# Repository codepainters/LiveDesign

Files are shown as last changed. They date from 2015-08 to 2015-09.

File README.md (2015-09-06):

Xilinx LiveDesing utils
-----------------------

This repository contains various files useful when working with
Xilinx version of the Altium LiveDesign board.

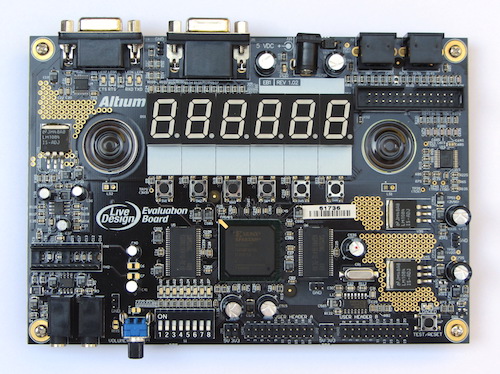
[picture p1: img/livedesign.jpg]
Altium board


The board is quite old, to be honest (I've bought mine a few years ago), 
but with Xilinx Spartan 3 FPGA (XC3S1000 in my case, there was also a smaller
XC3S400 edition) it is still quite powerful. It could have slightly better
peripherals, but well...

What's in this repo:

 * [docs](docs) - original docs from Altium
 * [jtag_pcb](jtag_pcb) - a project of small PCB converting Altium's silly 26-pin programming connector into standard Xilinx JTAG
 * [livedesign.ucf](livedesign.ucf) - UCF file for use with Xilinx WebPACK
 * [test](test) - simple test project

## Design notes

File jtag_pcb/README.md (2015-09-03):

This directory contains the schematic and PCB files for a simple 
JTAG pinout converter from Altium's to standard Xilinx 14-pin 
connector.

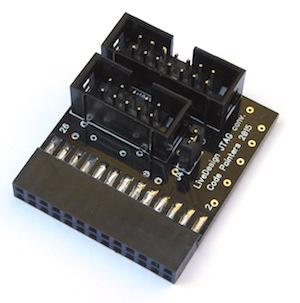
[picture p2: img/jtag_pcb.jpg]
JTAG PCB


Altium uses 26-pin IDC connector which maps directly to
a DB25 LPT plug. The pinout is as follows:

| Name | Pin | Pin | Name  |
|---|-----|-----|---|
| - | 1 | 2 | - |
| hTDI | 3 | 4 | hVREF |
| hTCK | 5 | 6 | - |
| hTMS | 7 | 8 | sTMS  |
| OE | 9 | 10  | GND |
| - | 11  | 12  | GND |
| sTDI | 13  | 14  | GND |
| - | 15  | 16  | GND |
| sTCK | 17  | 18  | GND |
| sTDO | 19  | 20  | GND |
| - | 21  | 22  | GND |
| - | 23  | 24  | GND |
| hTDO | 25  | 26  | - |

Note:
 
 * don't get confused by the pin numbering on the Altium schematics. They
   use the numbers corresponding to pins of the DB25 connector at 
   the other end of the flat cable. For normal IDC26 numbering use 
   the table above.

 * there are 2 sets of JTAG signals exposed - "hard" one is connected 
   to the FPGA's JTAG pins, this is the one to use to program the FPGA.
   Second one, referred to as "soft", is supposed to be used to debug 
   any soft-core CPU implemented in FPGA. It is connected to regular I/O
   pins: TMS - L21N, TCK - L24P, TDI - L21P, TDO - L17P.
 
 * pin 4 is pulled to `VCC` via 4k7 resistor, not sure what for, but 
   it seemed to be a good candidate for `VREF`. Unfortunately, it doesn't
   work as is (at least with the cable I use), see below.

 * pins 15, 21 and 23 are shorted together, but it's irrelevant for us

 * there is a 3-state buffer on board, OE connected to pin 9, it has 
   to be pulled low for anything to work 

The board is equipped with connectors for both JTAG chains:
 
 * IDC14 connector for "hard JTAG", compatible with Xilinx cables
 * IDC10 connector for "soft JTAG", using ARM JTAG pinout

The Xilinx cable requires 3.3V on JTAG `VREF` pin, and initially I planned
to use pin 4 as `VREF` source, unfortunately it doesn't work (scanning the chain,
as well as reading the ID etc. works fine, but actual programming fails).

There are two workarounds - one is to remove the `J4` jumper and connect
pin 2 of `J4` to any `VCC` point on LiveDesign board. Another workaround is to
short `R20S` on LiveDesign PCB.

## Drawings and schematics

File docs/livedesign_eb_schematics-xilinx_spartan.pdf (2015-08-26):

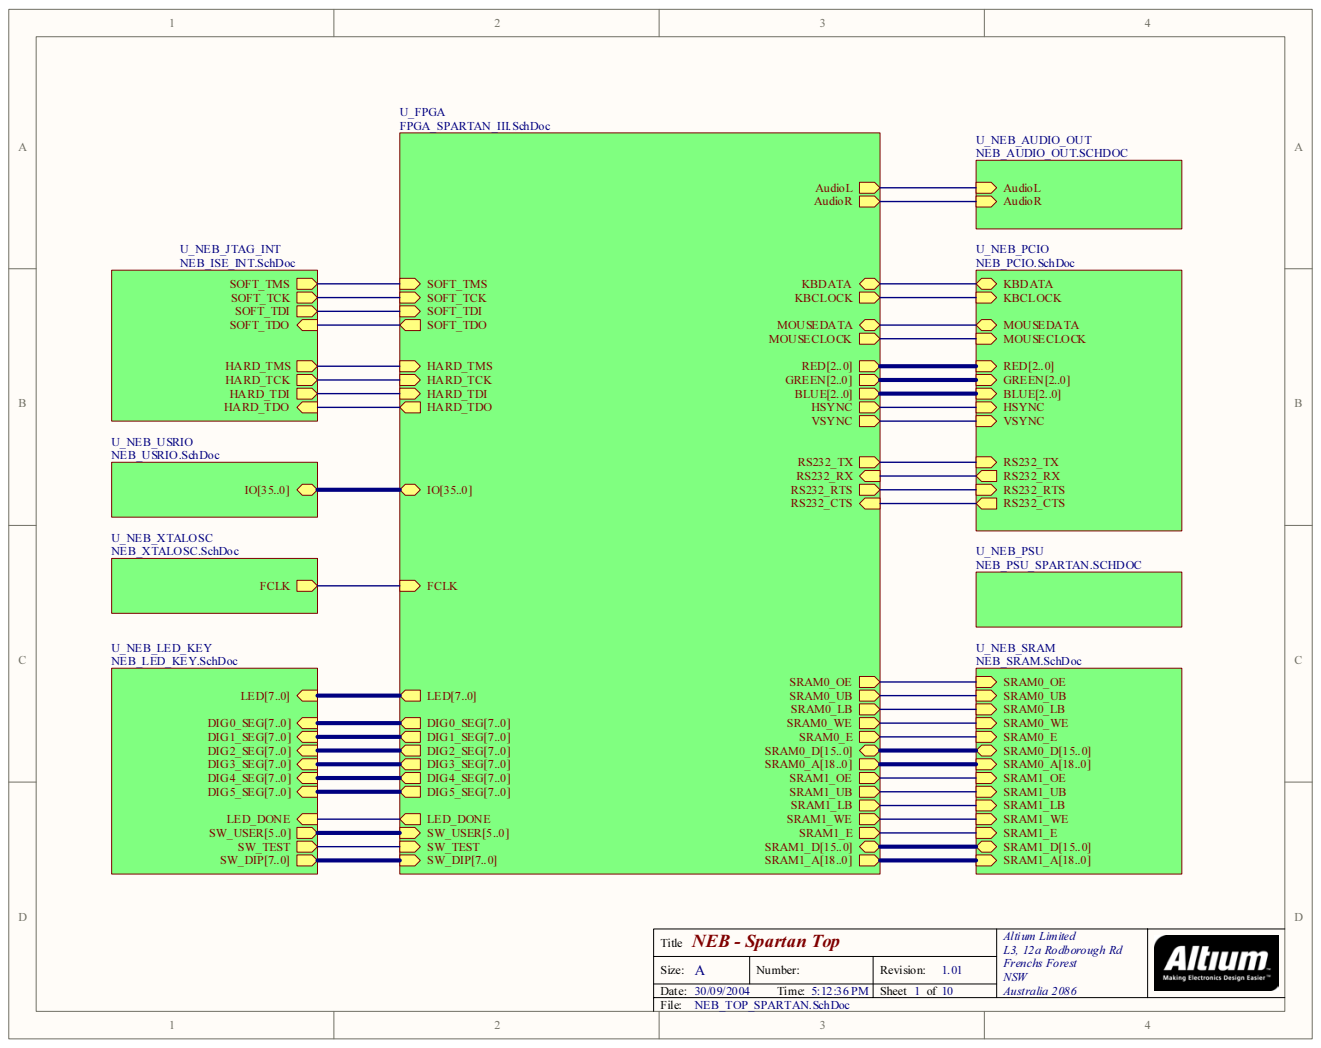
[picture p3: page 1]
Altium Limited L3, 12a Rodborough Rd Frenchs Forest NSW; Australia 2086; NEB_TOP_SPARTAN.SchDoc; Size:; Number:; Date: File:; Revision:; Time:; Sheet; SOFT_TCK SOFT_TDI; SOFT_TMS; SOFT_TDO; HARD_TMS HARD_TCK HARD_TDI HARD_TDO; U_NEB_JTAG_INT NEB_ISE_INT.SchDoc; AudioL AudioR; U_NEB_AUDIO_OUT NEB_AUDIO_OUT.SCHDOC; U_NEB_PSU NEB_PSU_SPARTAN.SCHDOC; LED[7..0]; SW_DIP[7..0]; DIG0_SEG[7..0] DIG1_SEG[7..0] DIG2_SEG[7..0] DIG3_SEG[7..0]; SW_TEST; SW_USER[5..0]; LED_DONE; DIG4_SEG[7..0] DIG5_SEG[7..0]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

NEB - Spartan Top
Title

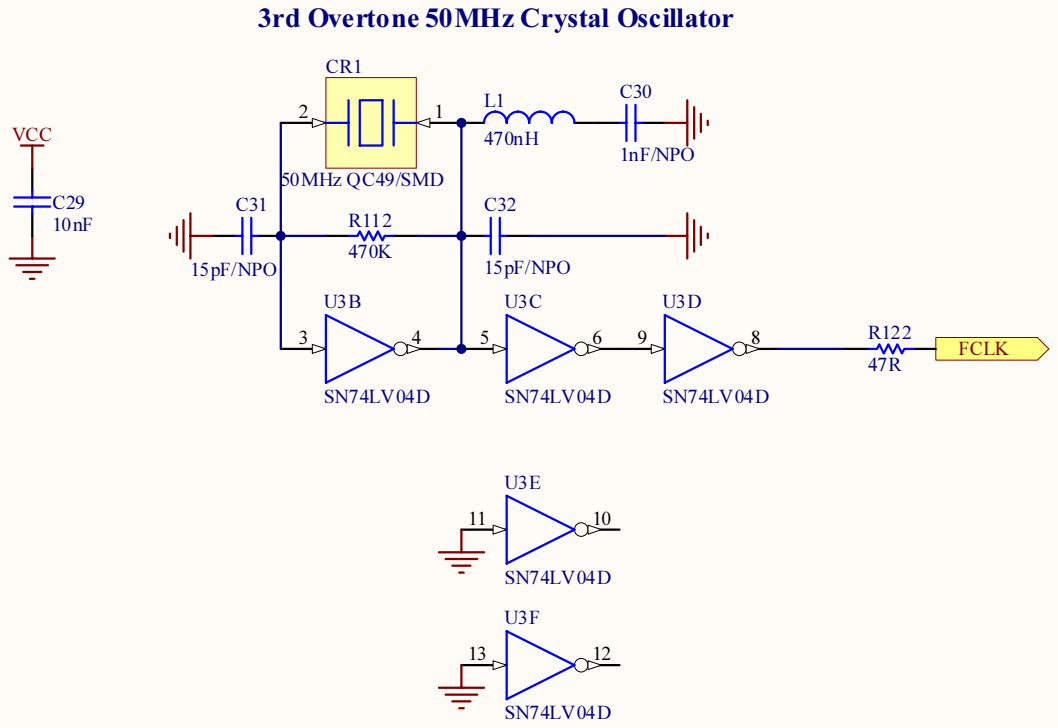
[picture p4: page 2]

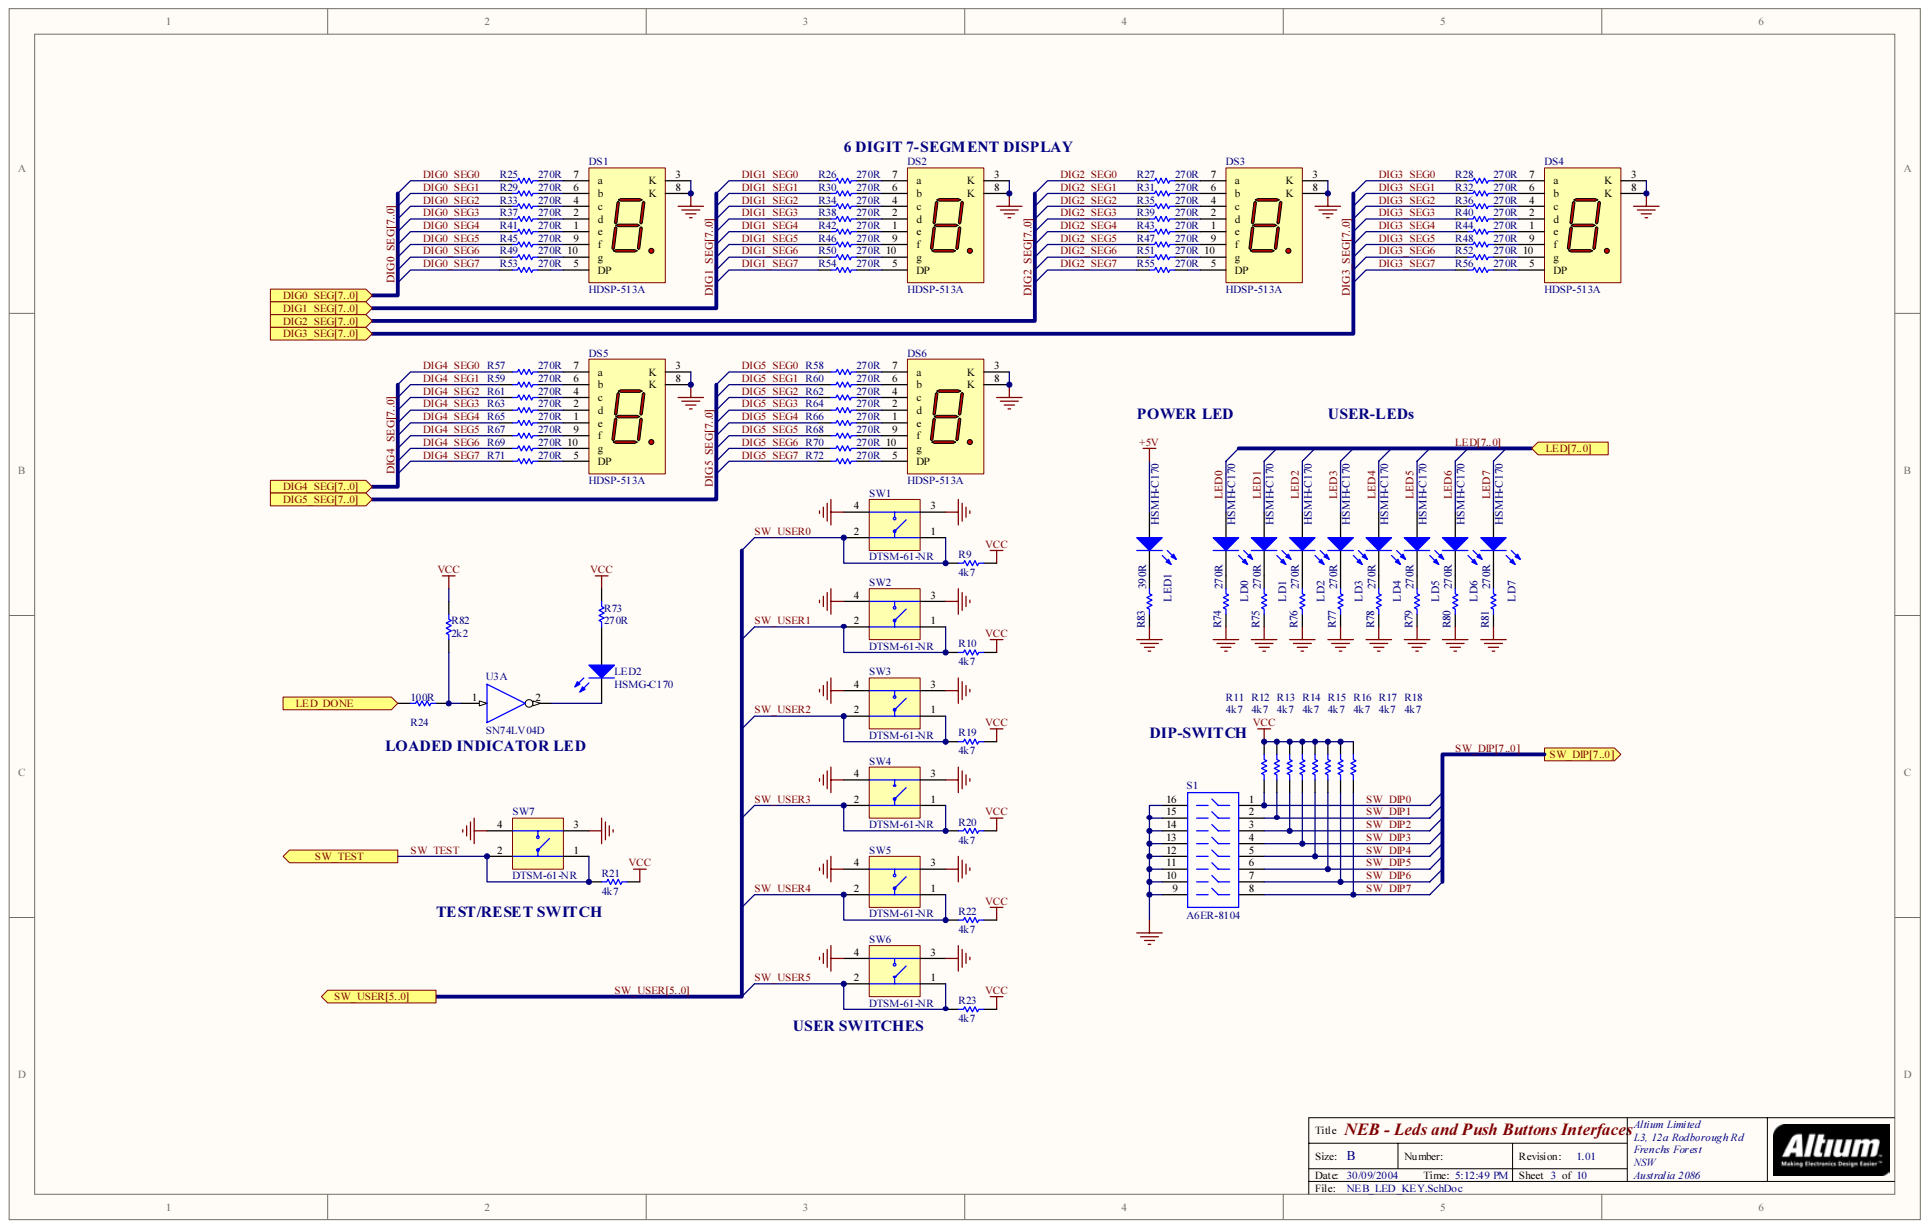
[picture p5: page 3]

NEB - Leds and Push Buttons Interfaces
Title

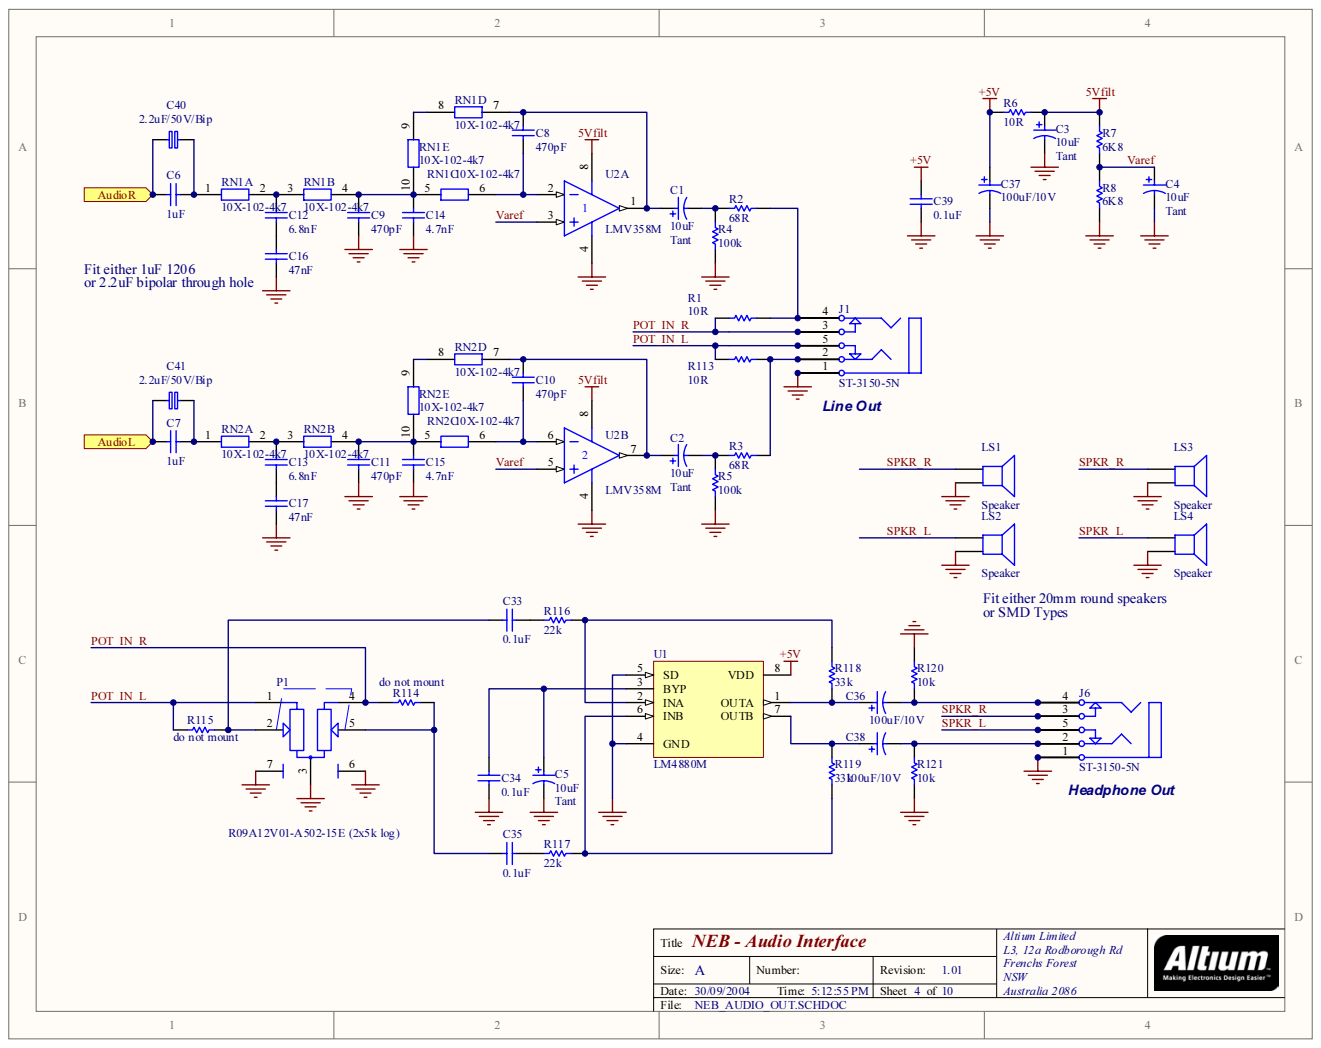
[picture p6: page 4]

Fit either 1uF 1206
or 2.2uF bipolar through hole

Speaker
Fit either 20mm round speakers
or SMD Types

# Printer Port JTAG Interface

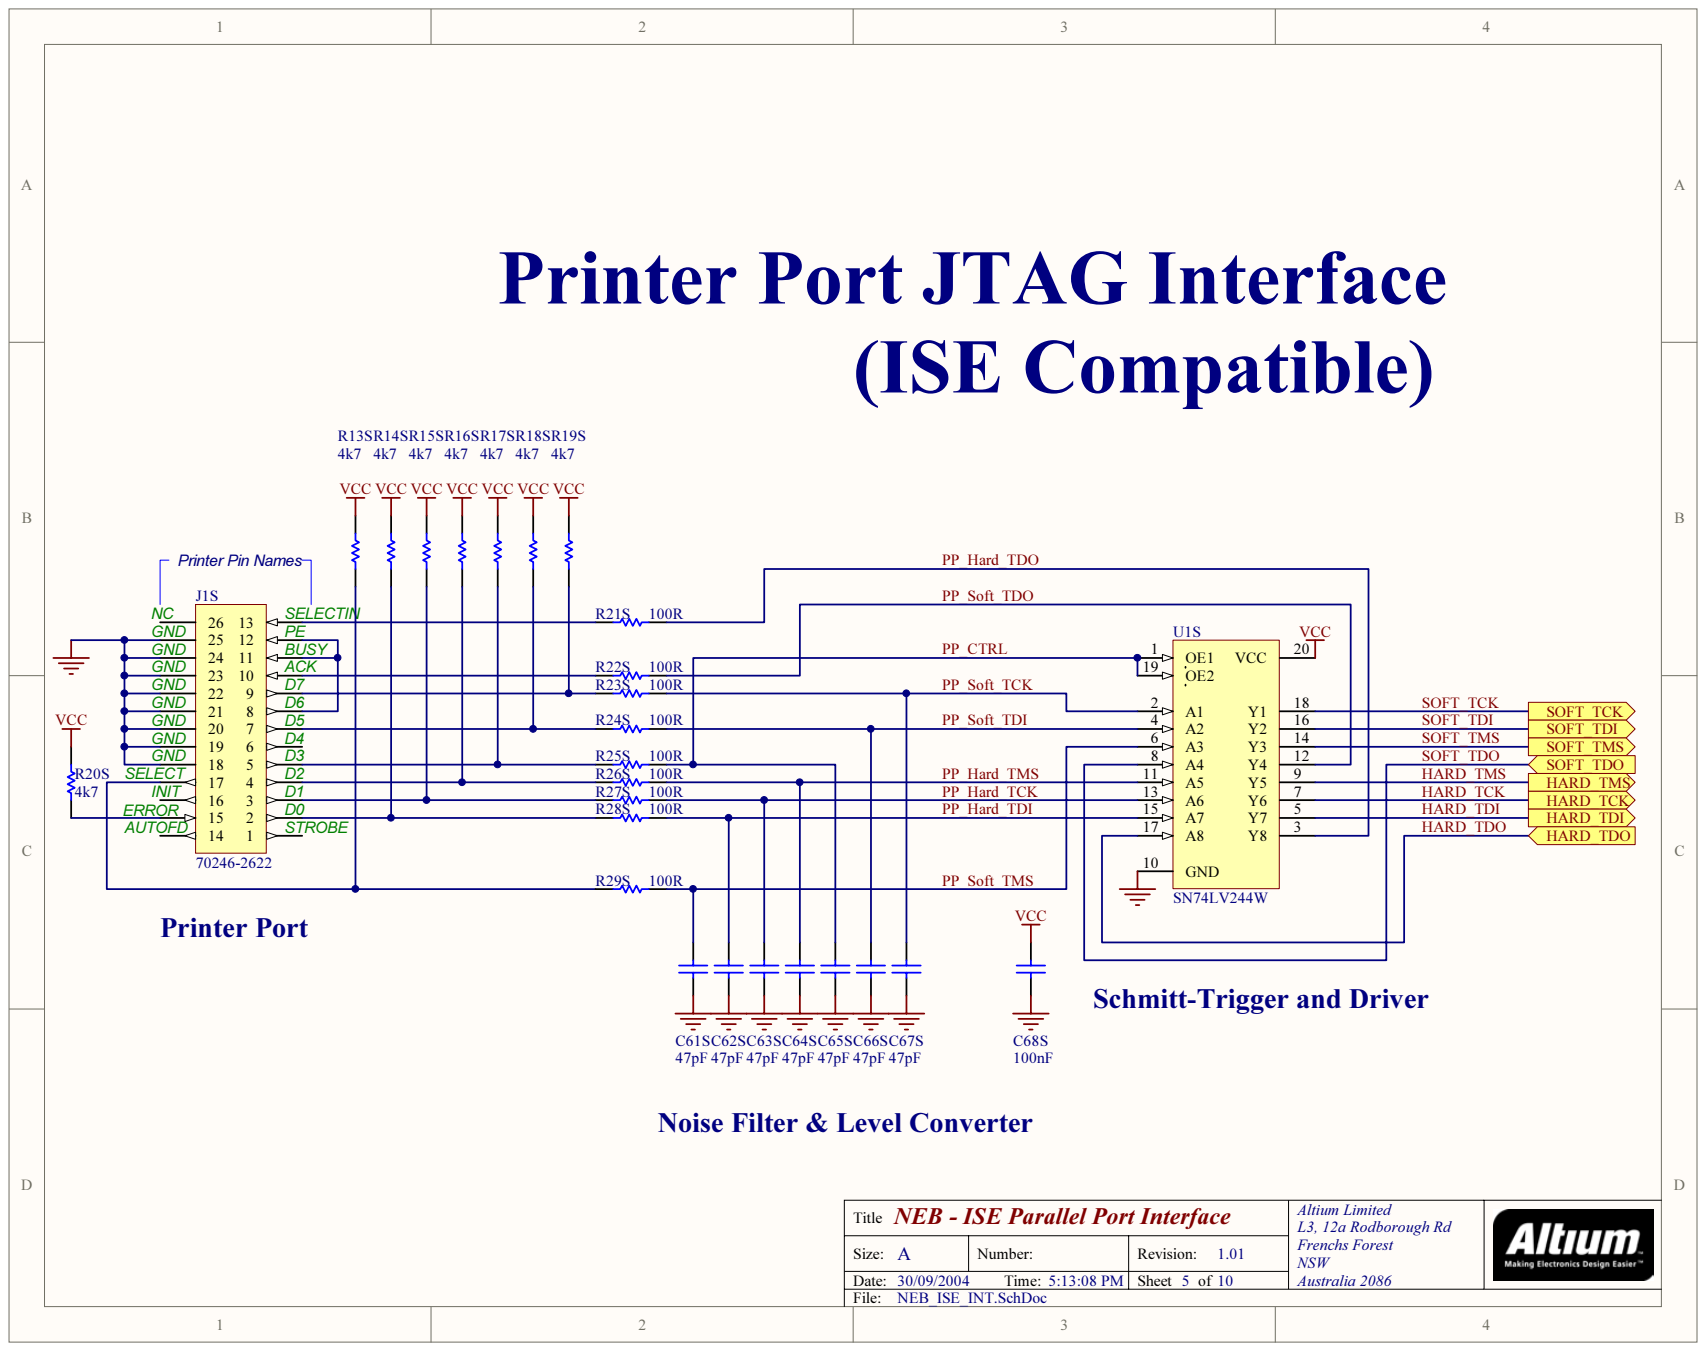
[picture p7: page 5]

PP_Soft_TDO

U1S PP_CTRL OE1 1 PP_Soft_TCK | VCC

Schmitt-Trigger and Driver

Noise Filter & Level Converter

NEB - ISE Parallel Port Interface

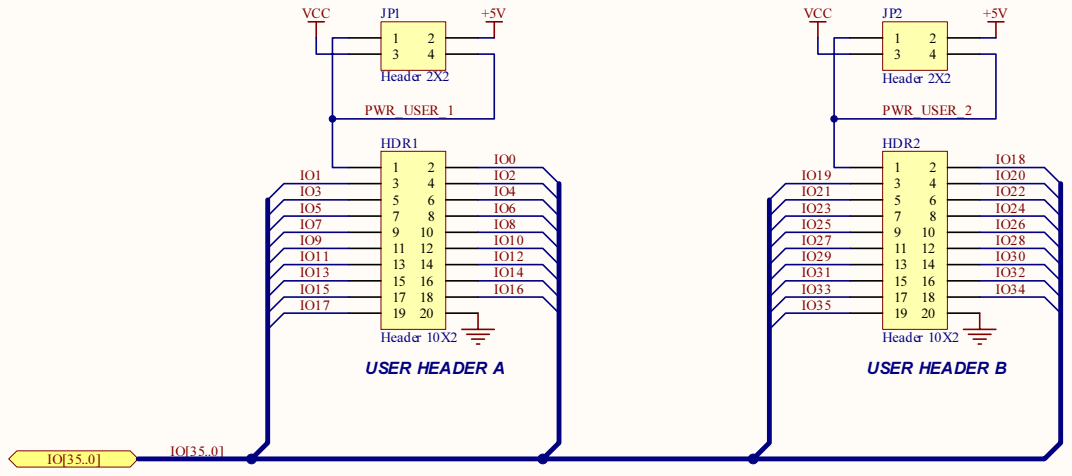
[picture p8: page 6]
Altium Limited L3, 12a Rodborough Rd Frenchs Forest; NEB_USRIO.SchDoc; Size:; Number:; Revision:; HDR1; Header 10X2; HDR2; VCC; USER HEADER A; USER HEADER B; Header 2X2; PWR_USER_1; PWR_USER_2

NEB - Users IO Interfaces
Title

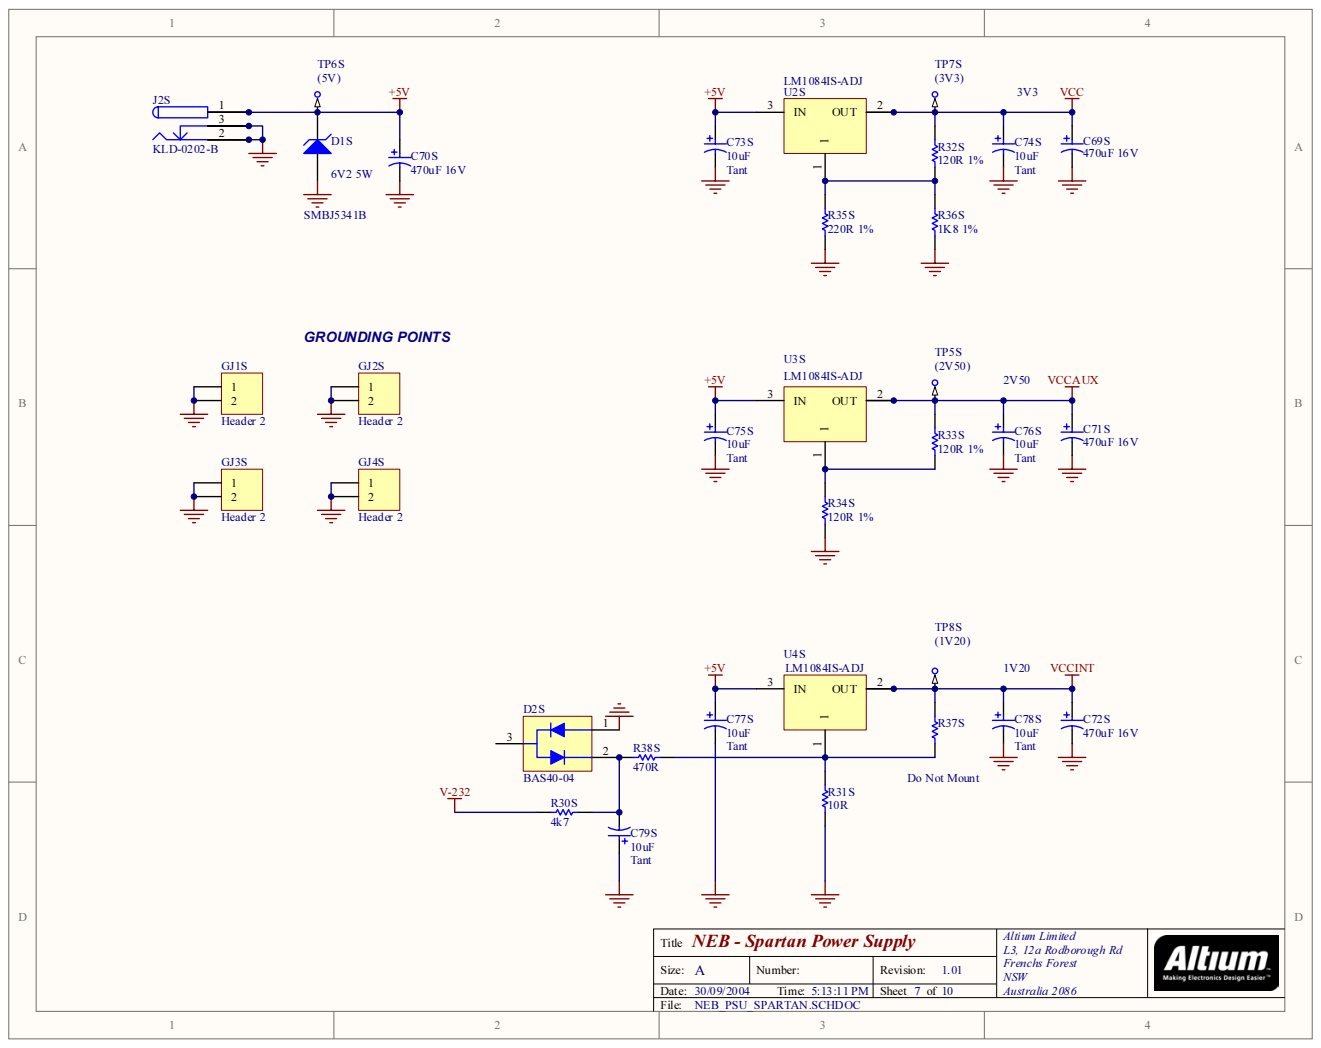
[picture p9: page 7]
Altium Limited L3, 12a Rodborough Rd Frenchs Forest; NEB_PSU_SPARTAN.SCHDOC; Size:; Number:; Revision:; VCC; Tant; VCCINT; Header 2; GROUNDING POINTS; VCCAUX; SMBJ5341B; KLD-0202-B; BAS40-04; OUT; LM1084IS-ADJ; U4S LM1084IS-ADJ; U3S LM1084IS-ADJ

Do Not Mount

NEB - Spartan Power Supply
Title

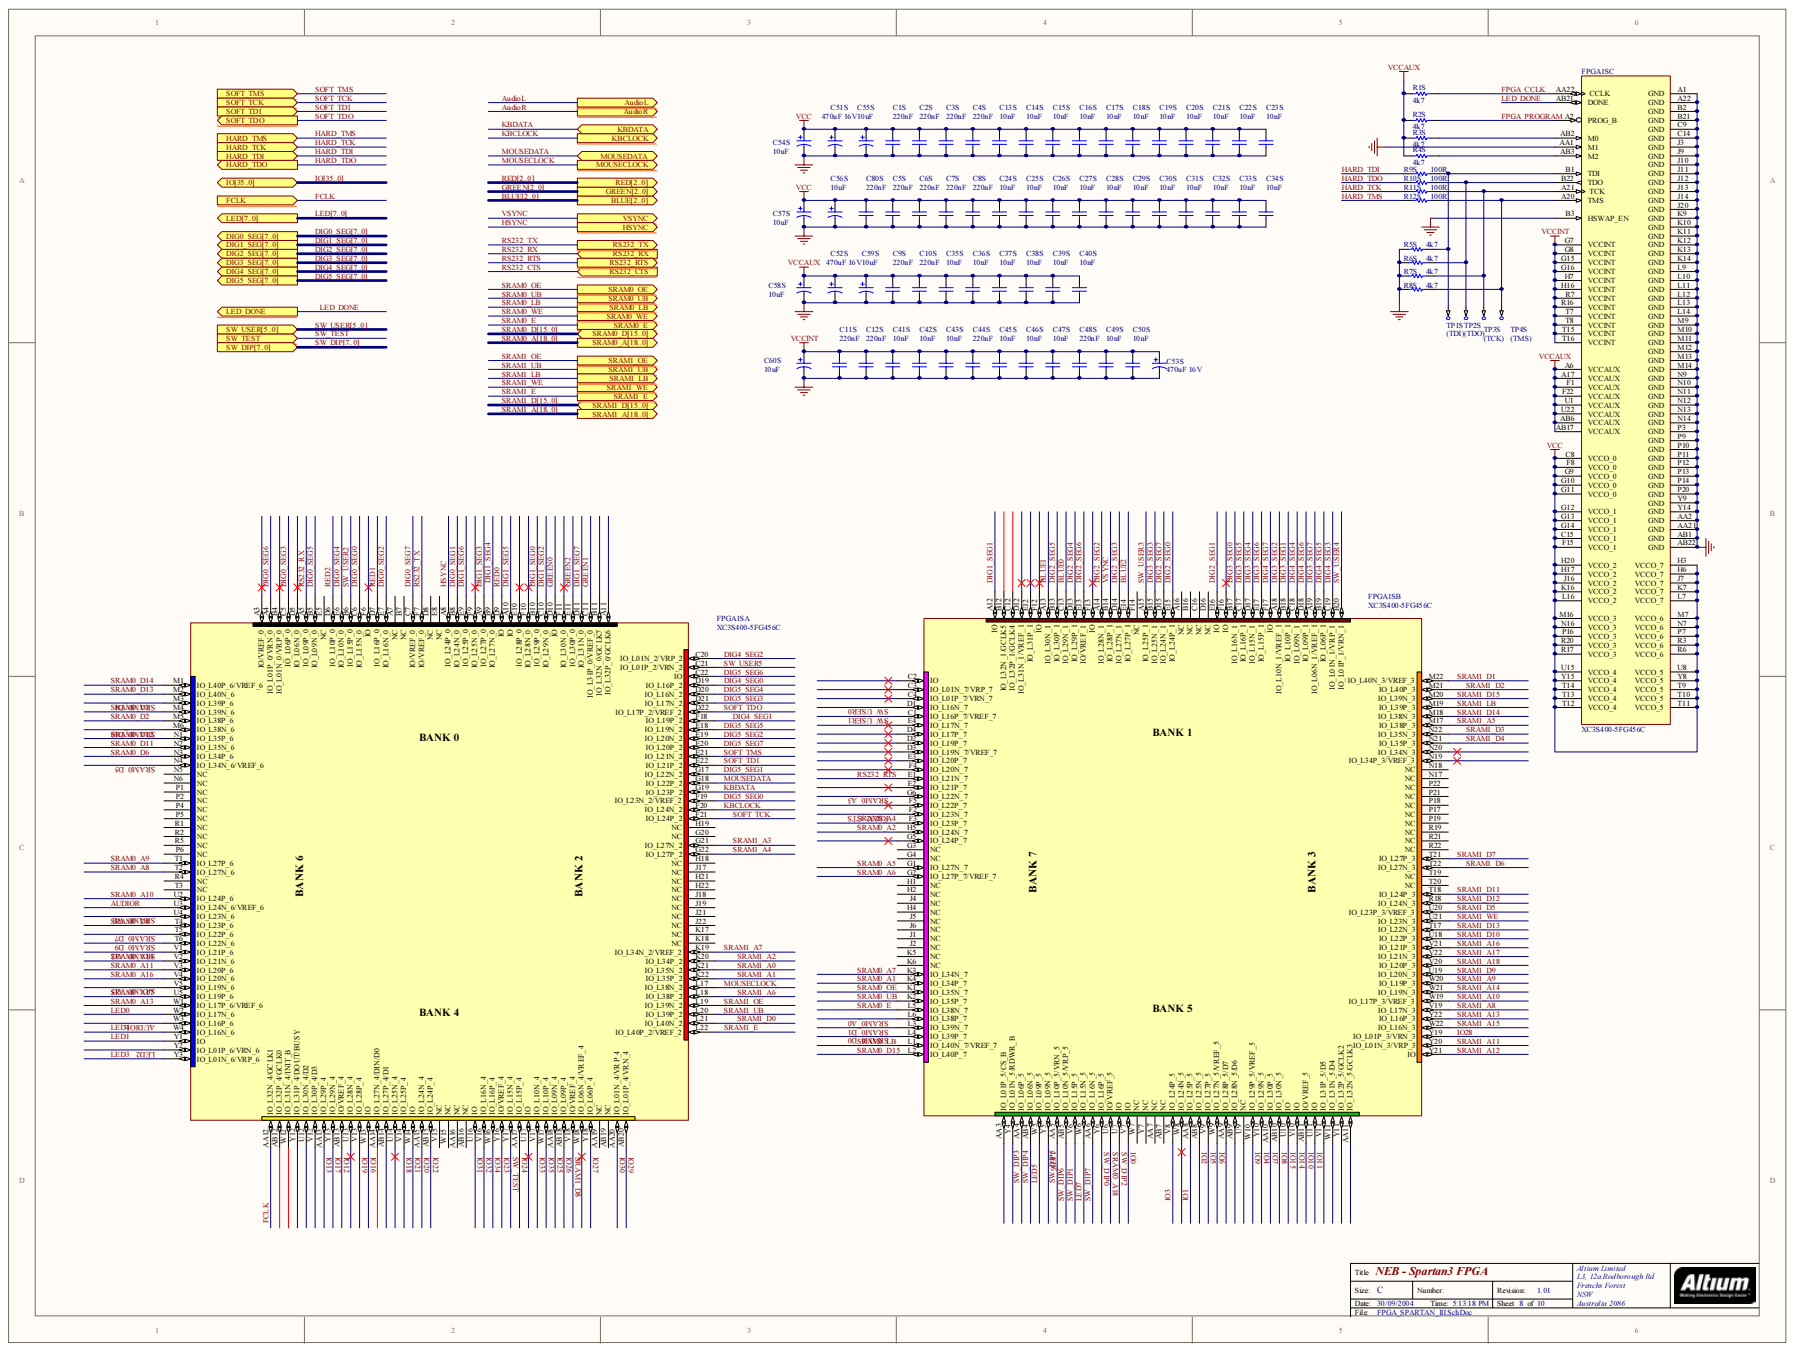
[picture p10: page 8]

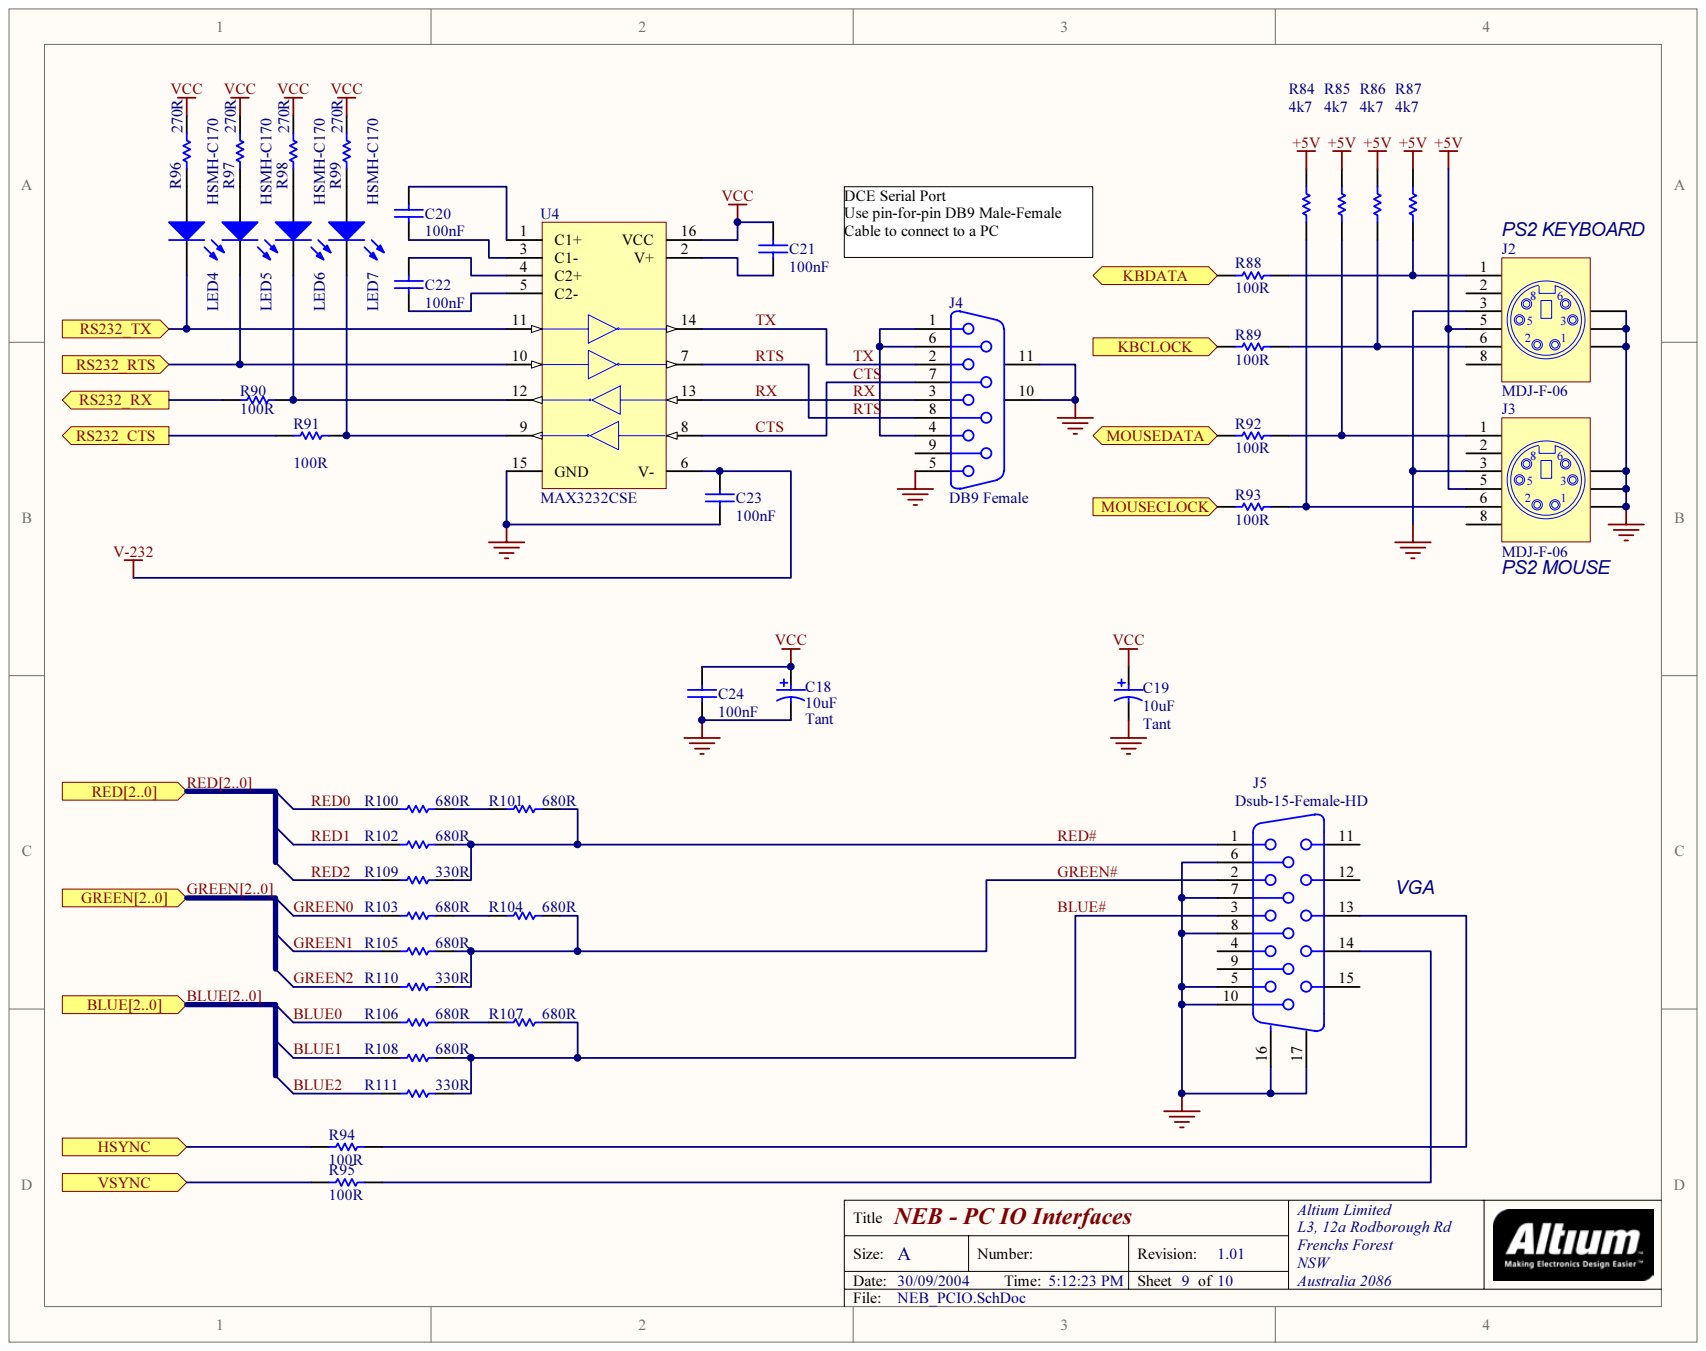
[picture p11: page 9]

DCE Serial Port
Use pin-for-pin DB9 Male-Female
Cable to connect to a PC

CTS | 7
RX RTS | 3 8

NEB - PC IO Interfaces

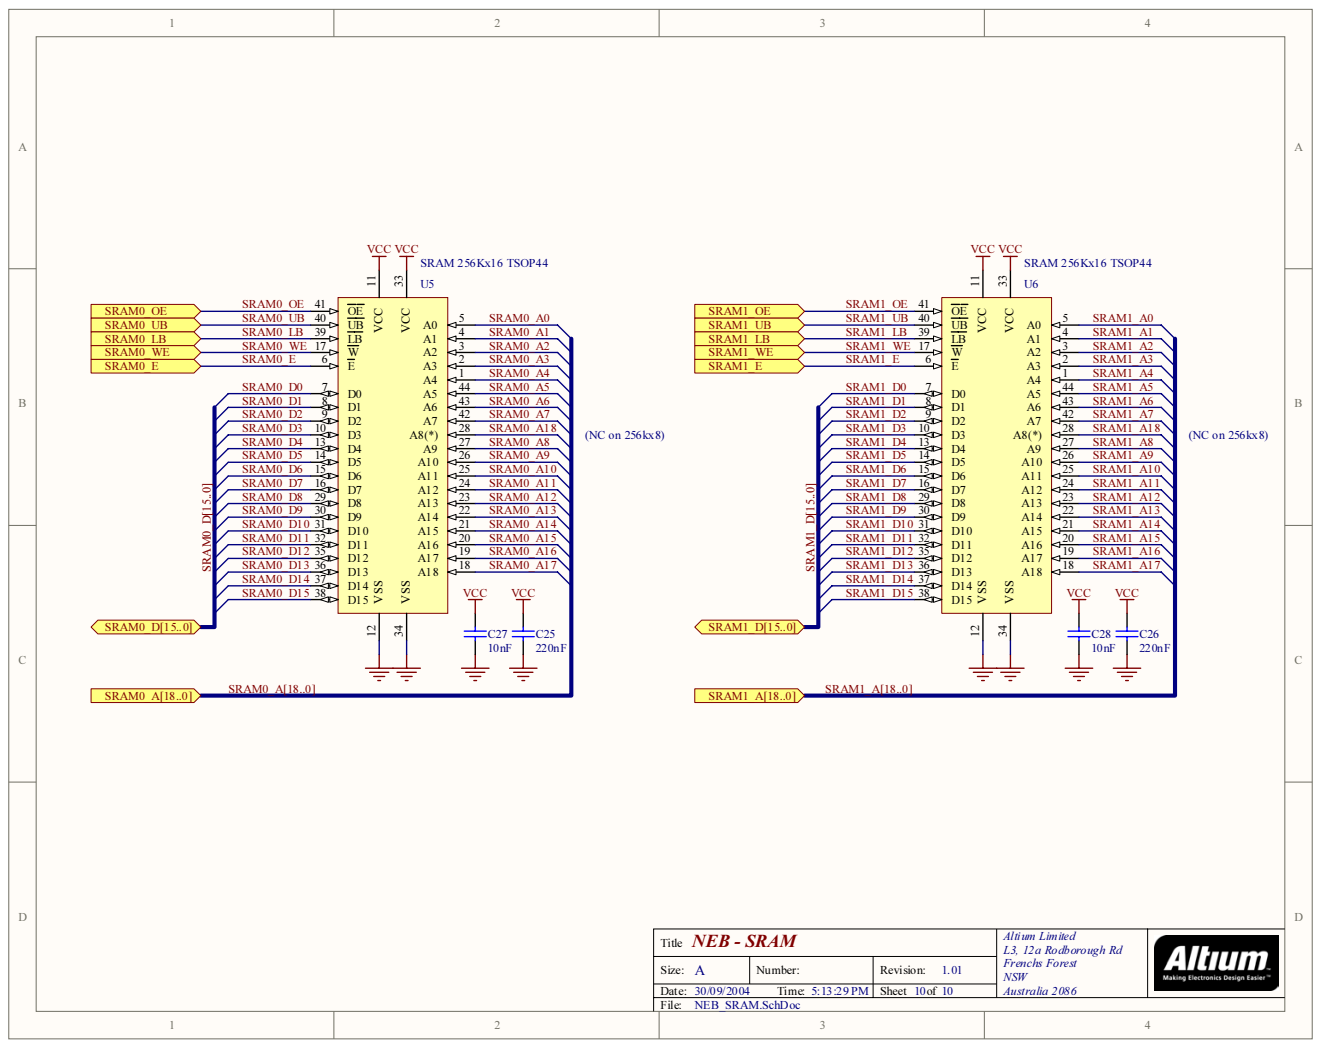
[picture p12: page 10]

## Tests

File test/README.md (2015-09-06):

Simple test project for LiveDesign board, compile with
Xilinx ISE WebPACK 14.7. 

What is tested:

 * user LEDs
 * DIP switches
 * 7-segment displays
 * push buttons below the displays
 * speakers
 * VGA output

TODO:

 * RS232 port
 * PS/2 ports
 * static RAMs

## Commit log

2015-08-10 IDC10/14/26 pin numbers fixed
2015-08-10 Schematic file complete
2015-08-10 PCB bootstrapped
2015-08-19 Board routed
2015-08-19 Fixed jumper fooprint (2.54 raster, not 2mm)
2015-08-19 Gerbers generated
    [jtag_pcb.drl, jtag_pcb_BoardOutline.gbr, jtag_pcb_Bottom.gbr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]
2015-08-19 Renamed Gerbers to DirtyPCB naming
    [jtag_pcb.gbl, jtag_pcb.gbr, jtag_pcb.gbs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]
2015-09-01 Added board picture to top-level README
2015-09-01 JTAG board picture added
2015-09-03 Test for LEDs and dip-switches
2015-09-03 Test for 7-segment displays and the buttons below
2015-09-03 Swapped left/right speaker in UCF (bug on Altium's schematics?)
2015-09-03 JTAG PCB README updated with VREF info
2015-09-06 VGA: switch controller color bars
2015-09-06 VGA: only switch colors during vsync pulse
2015-09-08 UART - direct loopback
2015-09-08 UART RX/TX code, untested
2015-09-09 UART loopback fixed
    Input to kcuart_tx must be valid for the whole char duration.
2015-09-09 UART: simple test, replace spaces with '@'
